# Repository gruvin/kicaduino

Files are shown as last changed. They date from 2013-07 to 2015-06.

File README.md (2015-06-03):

# KiCADuino
### A KiCAD version of the infamous Arduino UNO r3 PCB

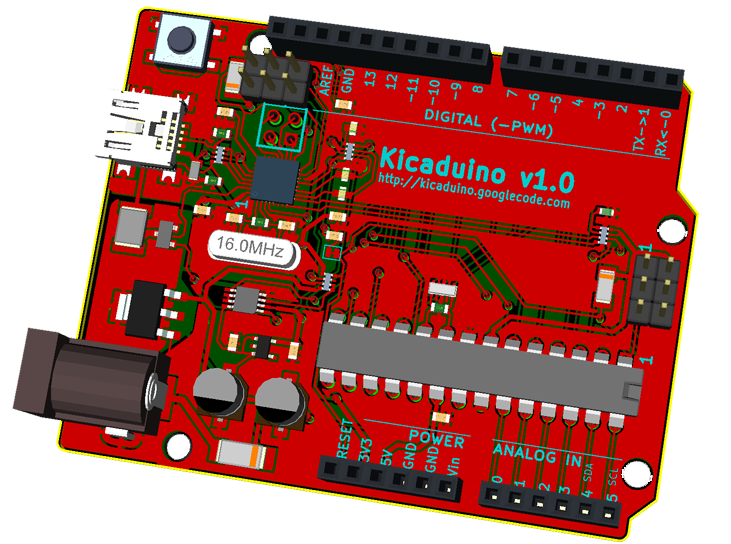
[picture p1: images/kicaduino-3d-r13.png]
There are too few, readily available and open projects in <a href='http://www.kicad-pcb.org'>KiCAD</a> 
format. I'm working to change that -- by taking some I like and re-creating them in KiCAD.

Why? Well, because it seemed a good idea and I seemed to have the time.

I'm starting with the good old Arduino UNO Rev.3, reference design. Obviously, my KiCAD version will not be an 
exact copy. In fact, I'll probably change the USB connector to USB-B-mini SMD. But otherwise, the circuitry 
will be the same, down to the socketed, DIP 'mega328. Maybe I'll do other versions later.

<blockquote>Arduino(TM) is a trademark of the owners of www.arduino.cc (they don't seem to have a name, other 
than Arduino -- even on their trademark information page). This KiCAD re-creation is by a 
separate individual, who is in no way related to the Arduino trademark owners or even likely 
known to them. Please see www.arduino.cc for all official Arduino(TM) information.</blockquote>

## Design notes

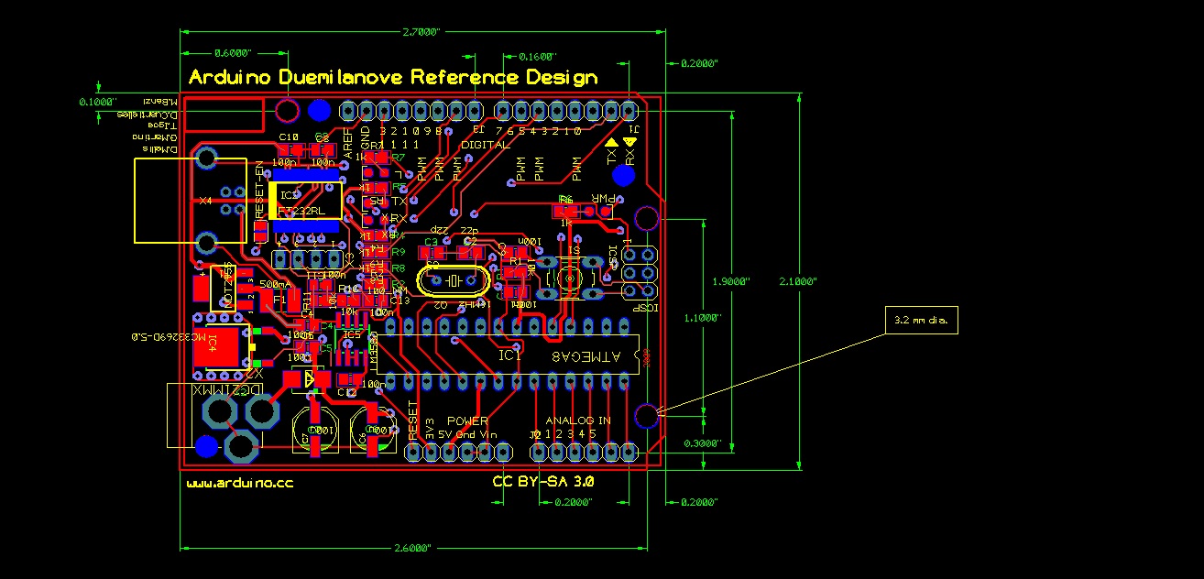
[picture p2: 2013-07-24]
uno/share/doc/Arduino Refererence Design.jpg

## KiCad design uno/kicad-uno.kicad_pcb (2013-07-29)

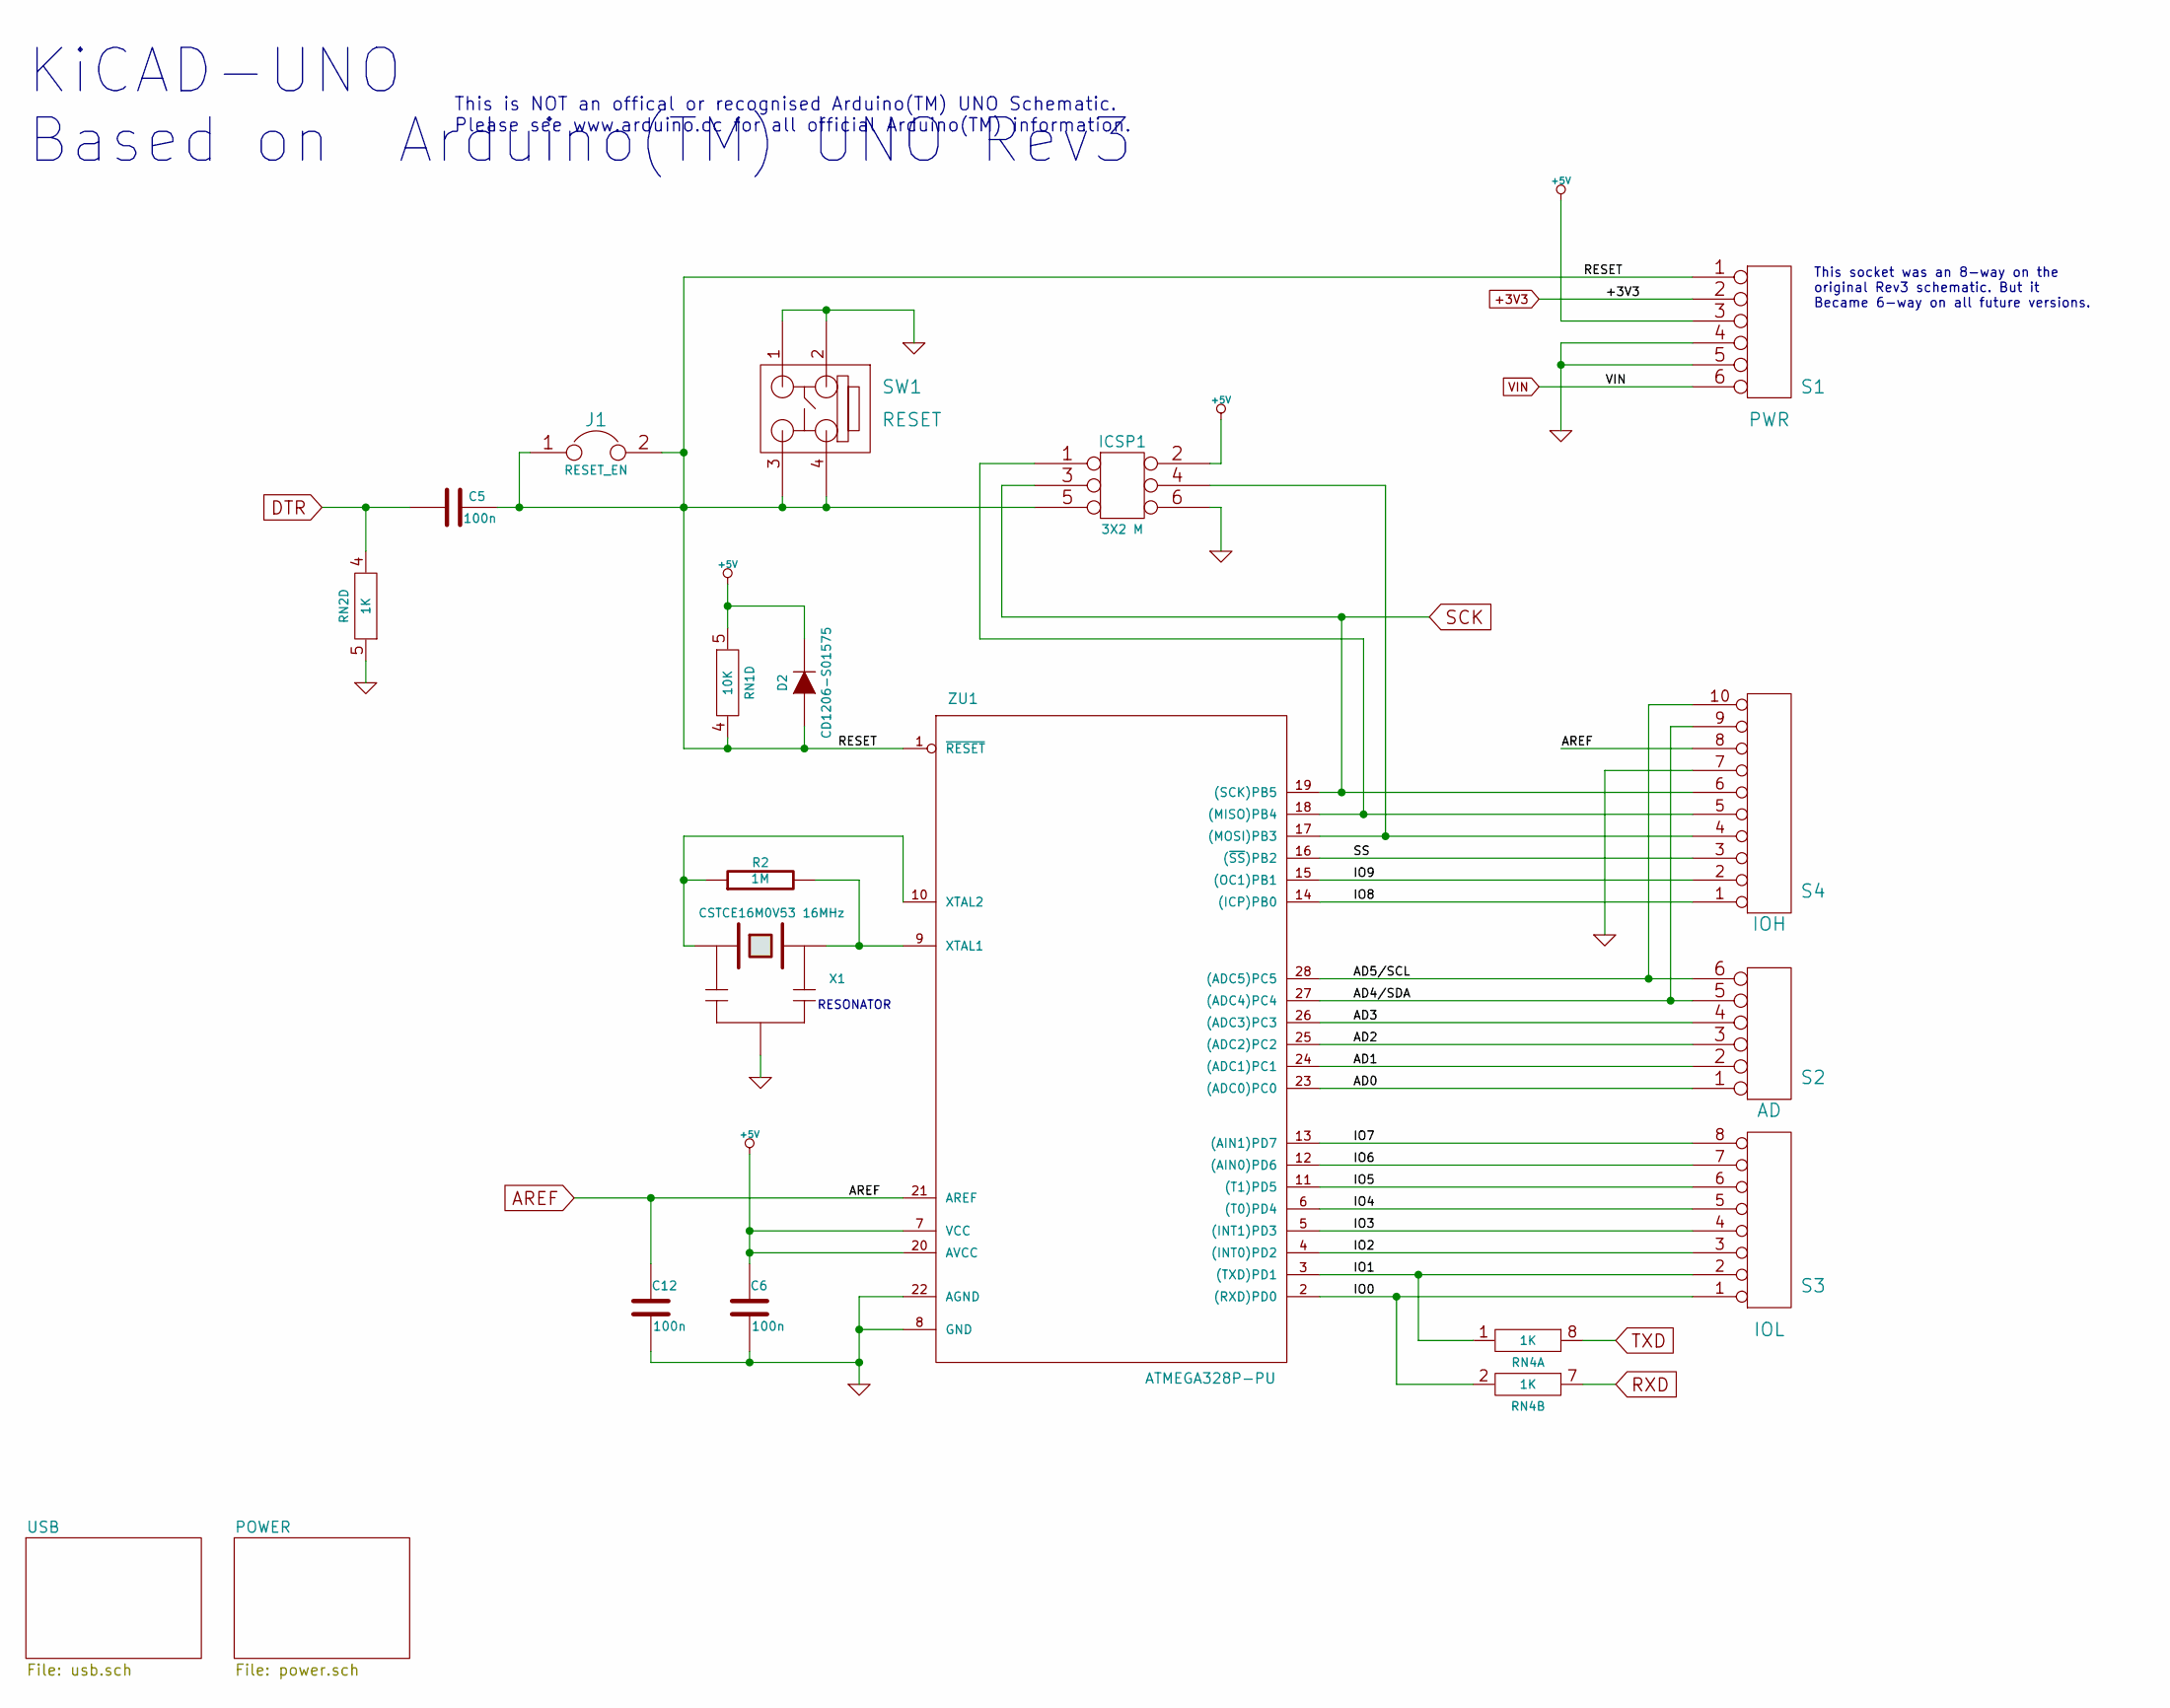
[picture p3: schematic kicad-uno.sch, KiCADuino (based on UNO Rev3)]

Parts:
C5, C6, C12: 100n; SM0603_Capa
D2: CD1206-S01575; SM1206D
ICSP1: 3X2 M; pin_array_3x2
J1: RESET_EN; JSOLD
R2: 1M
RN1: 10K
RN2, RN4: 1K
S1: PWR
S2: AD
S3: IOL
S4: IOH
SW1: RESET
X1: CSTCE16M0V53 16MHz
ZU1: ATMEGA328P-PU; DIP28

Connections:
+3V3: S1.2; also elsewhere on the board
+5V: C6.1, D2.2 (K), ICSP1.2, RN1.5 (6), S1.3, ZU1.7 (VCC), ZU1.20 (AVCC); also elsewhere on the board
/AD0: S2.1, ZU1.23 ((ADC0)PC0)
/AD1: S2.2, ZU1.24 ((ADC1)PC1)
/AD2: S2.3, ZU1.25 ((ADC2)PC2)
/AD3: S2.4, ZU1.26 ((ADC3)PC3)
/AD4/SDA: S2.5, S4.9, ZU1.27 ((ADC4)PC4)
/AD5/SCL: S2.6, S4.10, ZU1.28 ((ADC5)PC5)
/IO0: RN4.2 (3), S3.1, ZU1.2 ((RXD)PD0)
/IO1: RN4.1 (3), S3.2, ZU1.3 ((TXD)PD1)
/IO2: S3.3, ZU1.4 ((INT0)PD2)
/IO3: S3.4, ZU1.5 ((INT1)PD3)
/IO4: S3.5, ZU1.6 ((T0)PD4)
/IO5: S3.6, ZU1.11 ((T1)PD5)
/IO6: S3.7, ZU1.12 ((AIN0)PD6)
/IO7: S3.8, ZU1.13 ((AIN1)PD7)
/IO8: S4.1, ZU1.14 ((ICP)PB0)
/IO9: S4.2, ZU1.15 ((OC1)PB1)
/RESET: C5.2, D2.1 (A), ICSP1.5, J1.1, J1.2, RN1.4 (3), S1.1, SW1.3, SW1.4, ZU1.1 (~RESET)
/SS: S4.3, ZU1.16 ((~SS~)PB2)
AREF: C12.1, S4.8, ZU1.21 (AREF)
DTR: C5.1, RN2.4 (3); also elsewhere on the board
GND: C6.2, C12.2, ICSP1.6, RN2.5 (6), S1.4, S1.5, S4.7, SW1.1, SW1.2, X1.2, ZU1.8 (GND), ZU1.22 (AGND); also elsewhere on the board
unnamed: ICSP1.4, S4.4, ZU1.17 ((MOSI)PB3)
unnamed: ICSP1.1, S4.5, ZU1.18 ((MISO)PB4)
unnamed: R2.1, X1.1, ZU1.10 (XTAL2)
unnamed: R2.2, X1.3, ZU1.9 (XTAL1)
RXD: RN4.7 (6); also elsewhere on the board
SCK: ICSP1.3, S4.6, ZU1.19 ((SCK)PB5); also elsewhere on the board
TXD: RN4.8 (6); also elsewhere on the board
VIN: S1.6; also elsewhere on the board

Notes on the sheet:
RESONATOR
This is NOT an offical or recognised Arduino(TM) UNO Schematic. Please see www.arduino.cc for all official Arduino(TM) information.
KiCAD-UNO Based on Arduino(TM) UNO Rev3
This socket was an 8-way on the original Rev3 schematic. But it Became 6-way on all future versions.

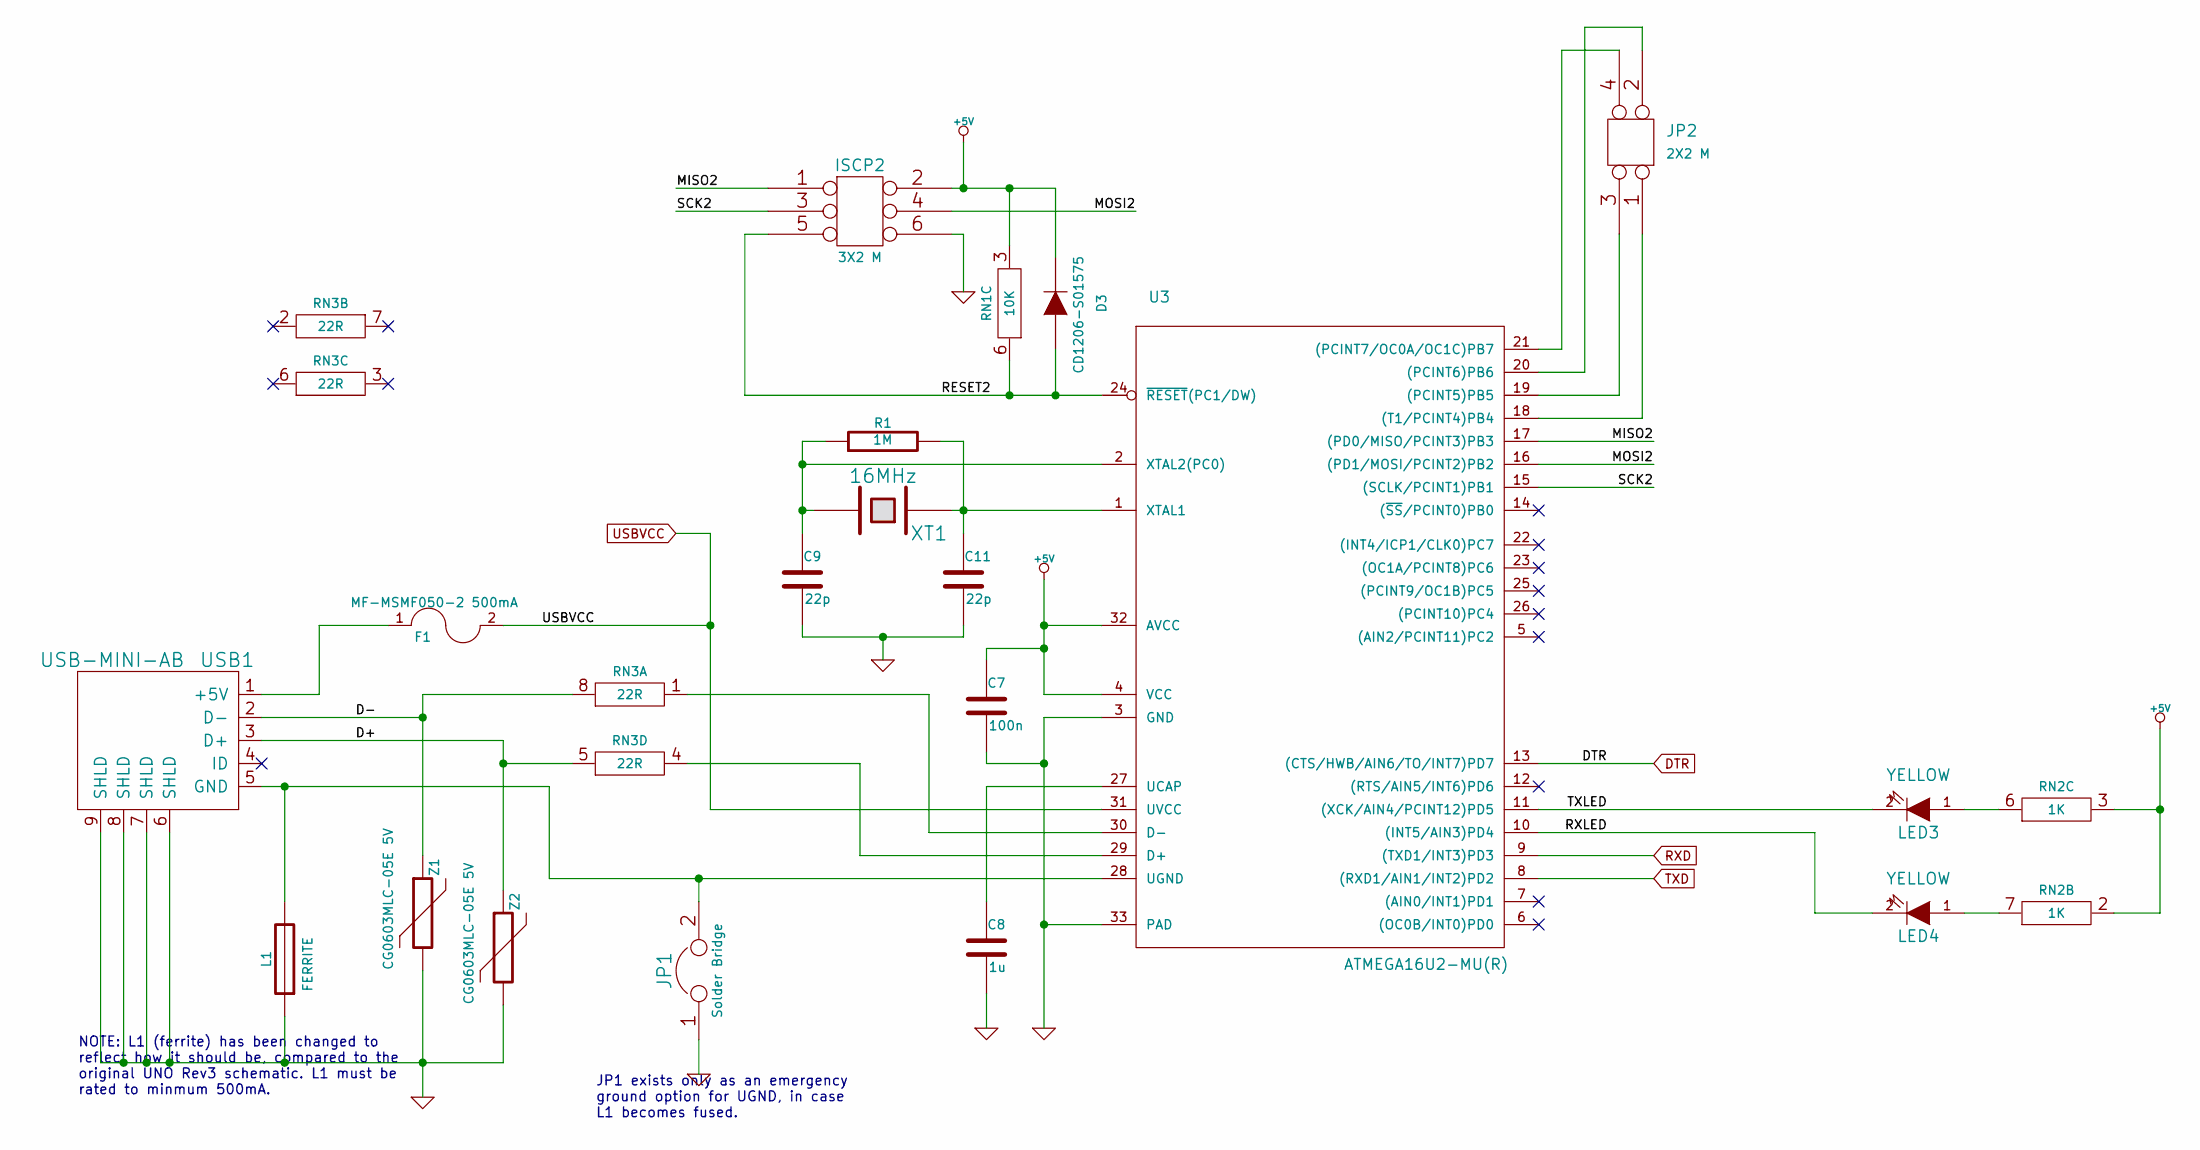
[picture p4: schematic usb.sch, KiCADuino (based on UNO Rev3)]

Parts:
C7: 100n; SM0603_Capa
C8: 1u; SM0603_Capa
C9, C11: 22p; SM0603_Capa
D3: CD1206-S01575; SM1206D
F1: MF-MSMF050-2 500mA; SM1812
ISCP2: 3X2 M; pin_array_3x2
JP1: Solder Bridge
JP2: 2X2 M; PIN_ARRAY_2X2
L1: FERRITE; SM0805
LED3, LED4: YELLOW
R1: 1M
RN1: 10K
RN2: 1K
RN3: 22R
U3: ATMEGA16U2-MU(R); QFN32
USB1: USB-MINI-AB
XT1: 16MHz
Z1, Z2: CG0603MLC-05E 5V

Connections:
+5V: C7.1, D3.2 (K), ISCP2.2, RN1.3, RN2.2 (3), RN2.3, U3.4 (VCC), U3.32 (AVCC); also elsewhere on the board
/USB/D+: RN3.5 (6), USB1.3 (D+), Z2.1
/USB/D-: RN3.8 (6), USB1.2 (D-), Z1.1
/USB/MISO2: ISCP2.1, U3.17 ((PD0/MISO/PCINT3)PB3)
/USB/MOSI2: ISCP2.4, U3.16 ((PD1/MOSI/PCINT2)PB2)
/USB/RESET2: D3.1 (A), ISCP2.5, RN1.6, U3.24 (~RESET~(PC1/DW))
/USB/RXLED: LED4.2 (K), U3.10 ((INT5/AIN3)PD4)
/USB/SCK2: ISCP2.3, U3.15 ((SCLK/PCINT1)PB1)
/USB/TXLED: LED3.2 (K), U3.11 ((XCK/AIN4/PCINT12)PD5)
DTR: U3.13 ((CTS/HWB/AIN6/TO/INT7)PD7); also elsewhere on the board
GND: C7.2, C8.2, C9.2, C11.2, ISCP2.6, JP1.1, L1.1, U3.3 (GND), U3.33 (PAD), USB1.6 (SHLD), USB1.7 (SHLD), USB1.8 (SHLD), USB1.9 (SHLD), Z1.2, Z2.2; also elsewhere on the board
unnamed: JP2.4, U3.21 ((PCINT7/OC0A/OC1C)PB7)
unnamed: JP2.3, U3.19 ((PCINT5)PB5)
unnamed: JP2.2, U3.20 ((PCINT6)PB6)
unnamed: C8.1, U3.27 (UCAP)
unnamed: JP2.1, U3.18 ((T1/PCINT4)PB4)
unnamed: LED3.1 (A), RN2.6
unnamed: F1.1, USB1.1 (+5V)
unnamed: LED4.1 (A), RN2.7 (6)
unnamed: RN3.4 (3), U3.29 (D+)
unnamed: RN3.1 (3), U3.30 (D-)
unnamed: C9.1, R1.1, U3.2 (XTAL2(PC0)), XT1.2
unnamed: C11.1, R1.2, U3.1 (XTAL1), XT1.1
unnamed: JP1.2, L1.2, U3.28 (UGND), USB1.5 (GND)
RXD: U3.9 ((TXD1/INT3)PD3); also elsewhere on the board
TXD: U3.8 ((RXD1/AIN1/INT2)PD2); also elsewhere on the board
USBVCC: F1.2, U3.31 (UVCC); also elsewhere on the board

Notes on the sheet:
NOTE: L1 (ferrite) has been changed to reflect how it should be, compared to the original UNO Rev3 schematic. L1 must be rated to minmum 500mA.
JP1 exists only as an emergency ground option for UGND, in case L1 becomes fused.

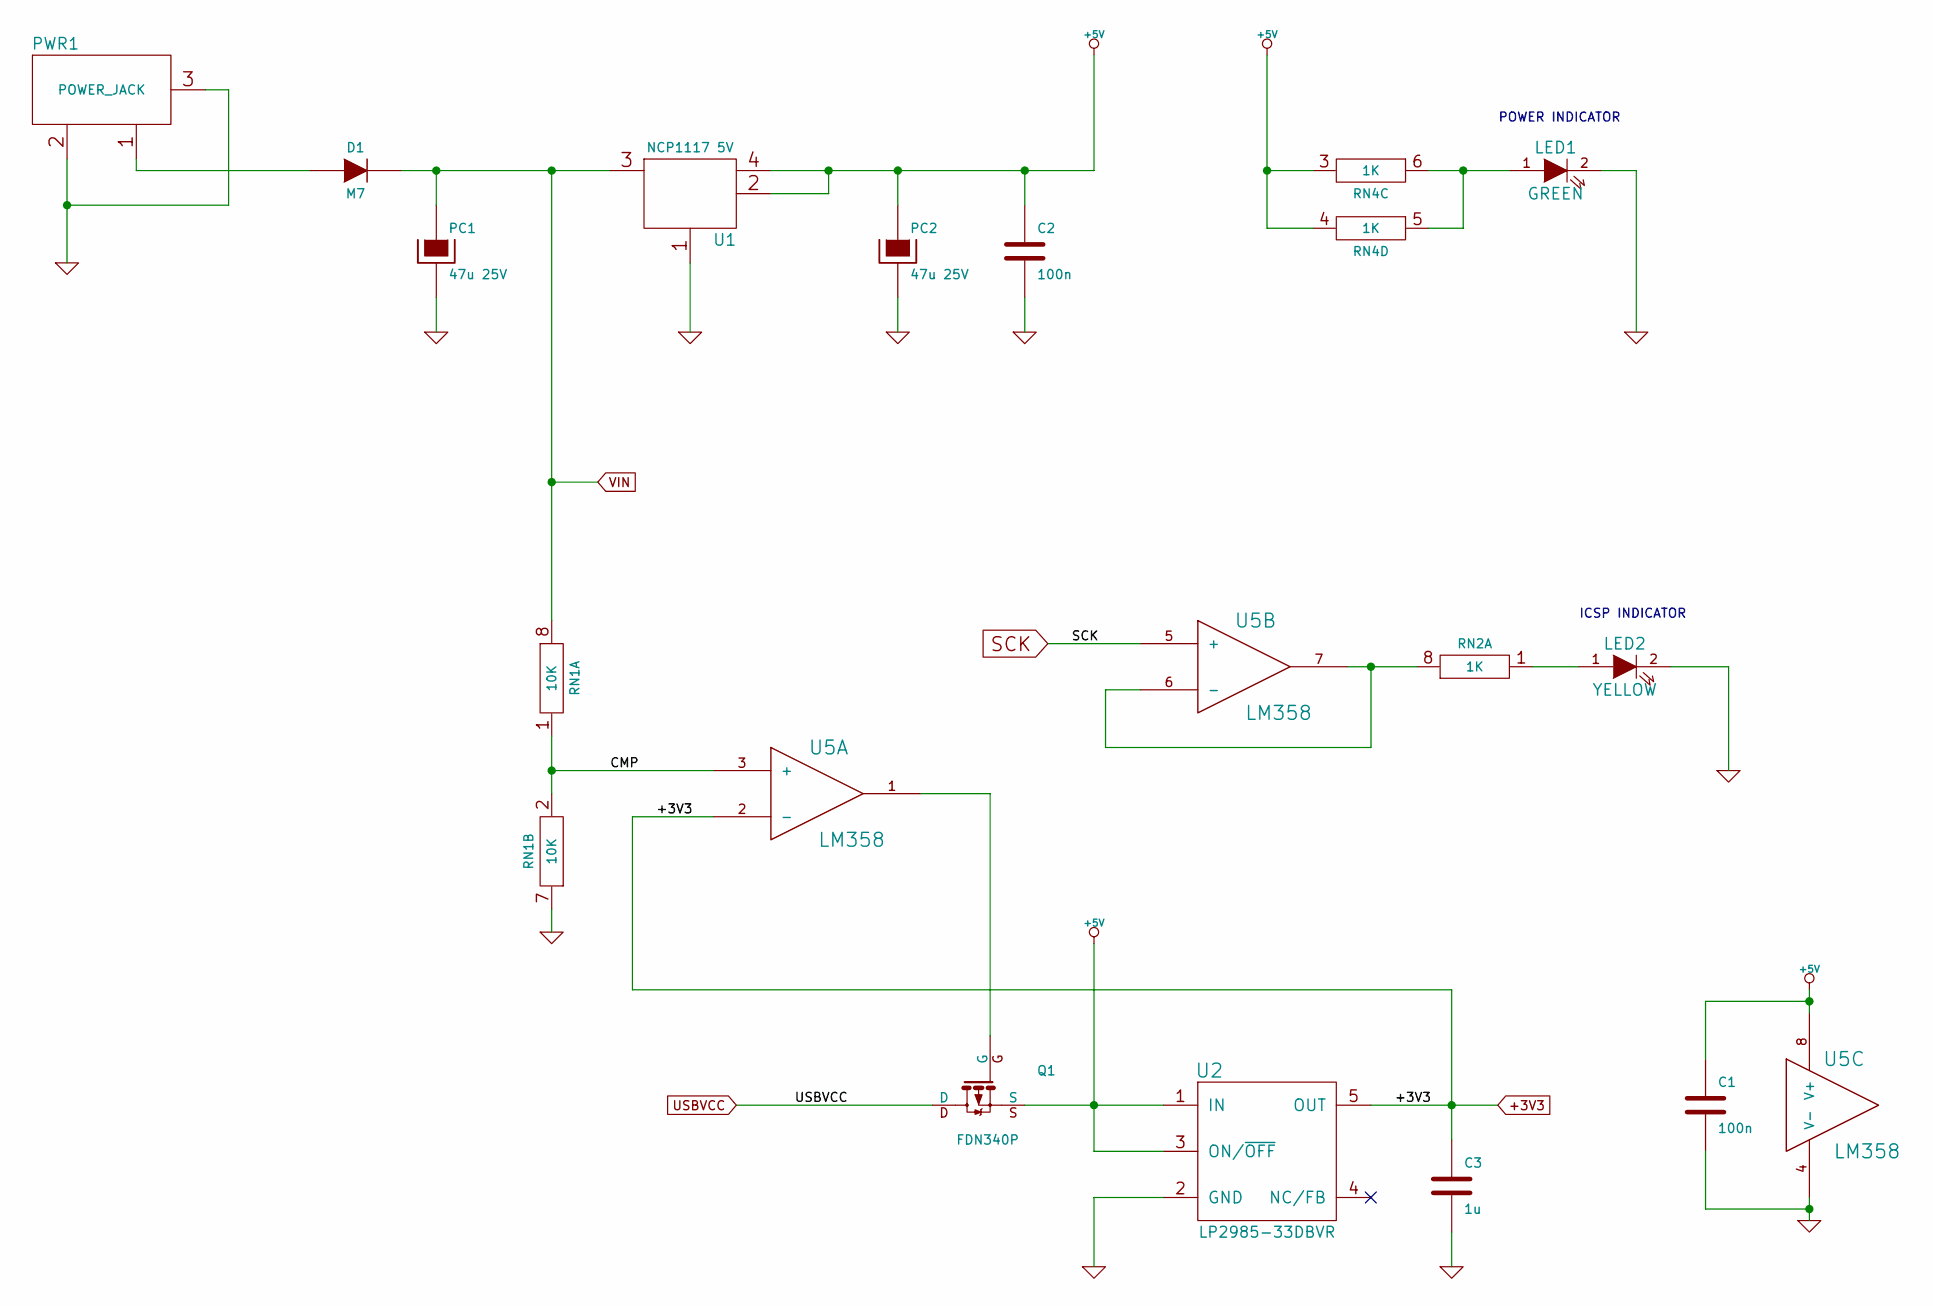
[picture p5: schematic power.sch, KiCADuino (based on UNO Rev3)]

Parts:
C1, C2: 100n; SM0603_Capa
C3: 1u; SM0603_Capa
D1: M7; DO-214AC
LED1: GREEN; LED_0603_GREEN
LED2: YELLOW
PC1, PC2: 47u 25V
PWR1: POWER_JACK
Q1: FDN340P; SOT23
RN1: 10K
RN2, RN4: 1K
U1: NCP1117 5V
U2: LP2985-33DBVR
U5: LM358

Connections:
+3V3: C3.1, U2.5 (OUT), U5.2 (-); also elsewhere on the board
+5V: C1.1, C2.1, PC2.1, Q1.S, RN4.3, RN4.4 (3), U1.2 (PM), U1.4 (OUT), U2.1 (IN), U2.3 (ON/~OFF~), U5.8 (V+); also elsewhere on the board
/POWER/CMP: RN1.1 (3), RN1.2 (3), U5.3 (+)
GND: C1.2, C2.2, C3.2, LED1.2 (K), LED2.2 (K), PC1.2, PC2.2, PWR1.2, PWR1.3, RN1.7 (6), U1.1 (GND), U2.2 (GND), U5.4 (V-); also elsewhere on the board
unnamed: Q1.G, U5.1
unnamed: LED2.1 (A), RN2.1 (3)
unnamed: RN2.8 (6), U5.6 (-), U5.7
unnamed: LED1.1 (A), RN4.5 (6), RN4.6
unnamed: D1.1 (A), PWR1.1
SCK: U5.5 (+); also elsewhere on the board
USBVCC: Q1.D; also elsewhere on the board
VIN: D1.2 (K), PC1.1, RN1.8 (6), U1.3 (IN); also elsewhere on the board

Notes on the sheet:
POWER INDICATOR
ICSP INDICATOR

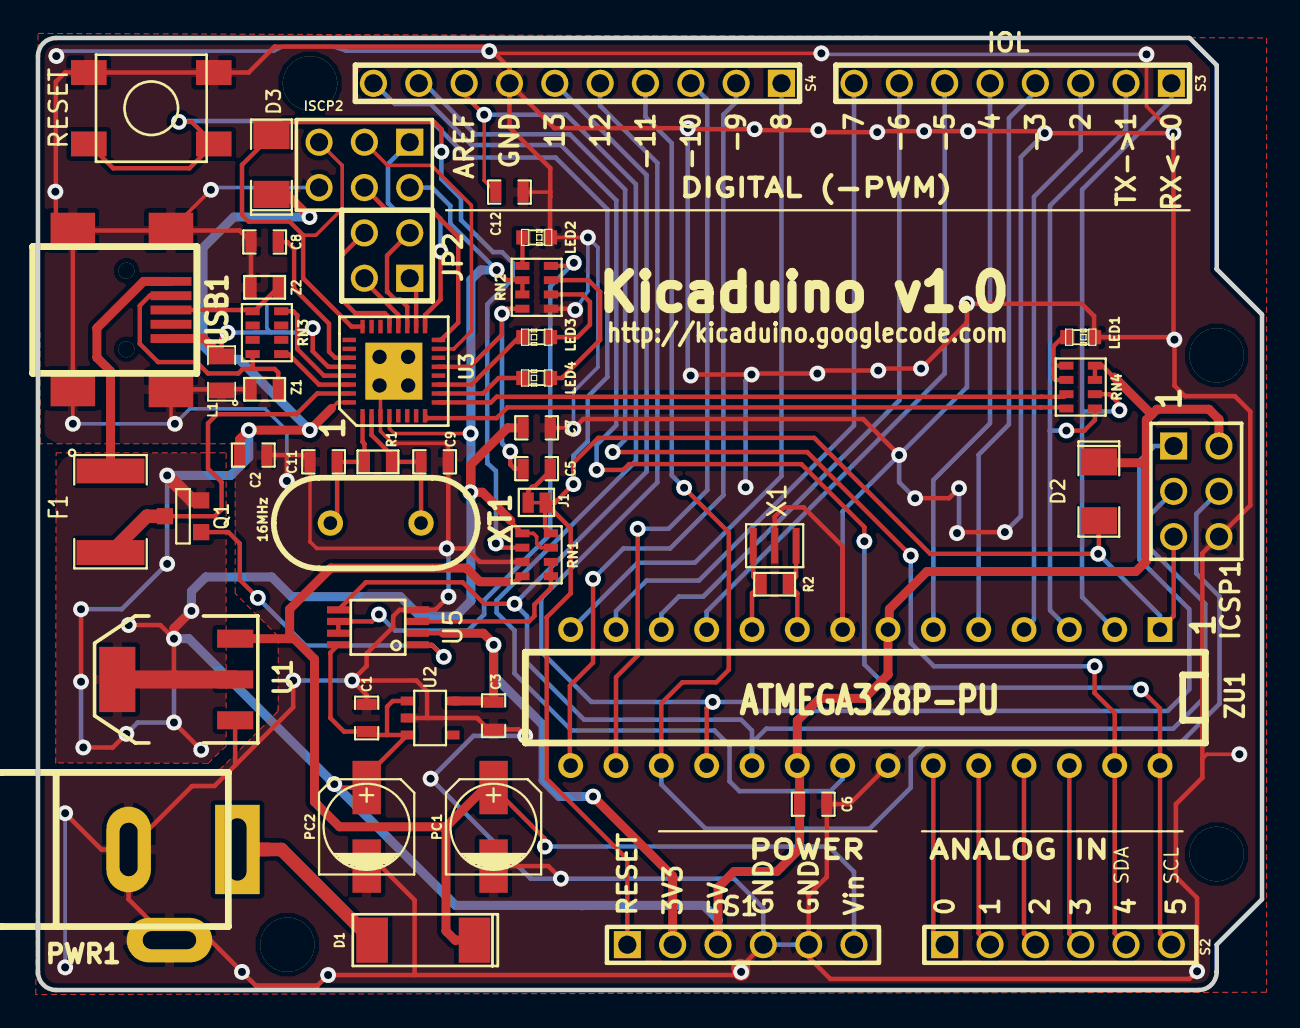
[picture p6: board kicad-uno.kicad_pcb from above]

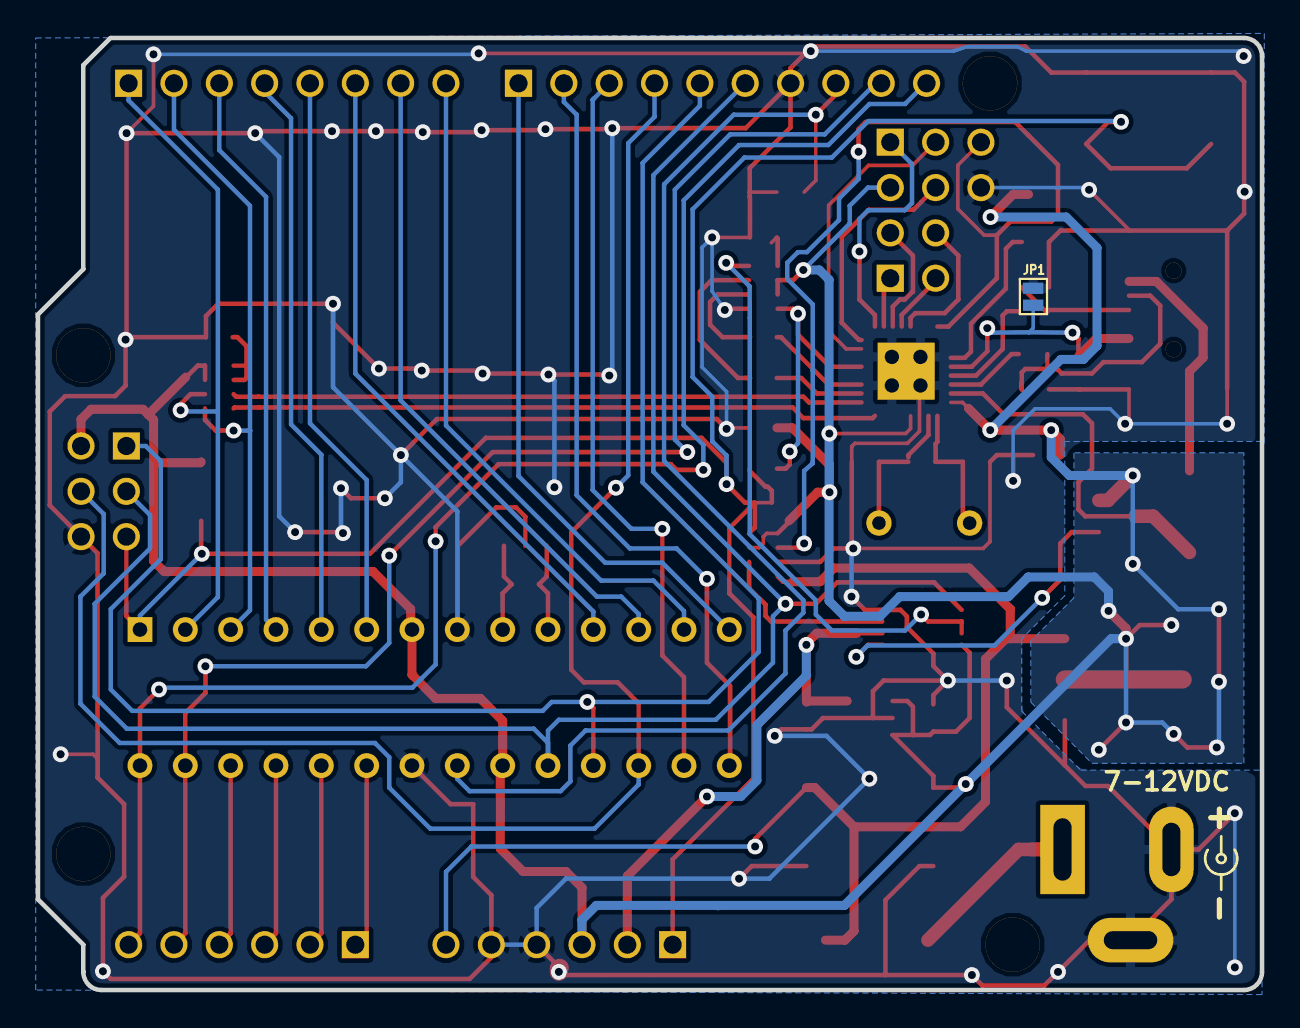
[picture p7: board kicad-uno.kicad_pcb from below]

Board: 2 copper layers, 68.6 x 53.3 mm, 54 parts (2 on the bottom side), 59 nets.

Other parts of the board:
HOLE_130x130mil, HOLE_130x130mil#2, HOLE_130x130mil#3, HOLE_130x250mil: VAL**; HOLE_120x120mil
REF: VAL**; POWER_POLARITY_REF

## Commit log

2013-07-24 Schematic ERC passes. Circuit _might_ be complete, without errors. You just never know. :-P
    [kicad-uno.sch, power.sch, usb.sch]
2013-07-25 Component packages configured.
    PCB initial placement.
    Some minor typo corrections.
    [kicad-uno.kicad_pcb, kicad-uno.sch, power.sch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]
2013-07-25 Added resistor network part/module for RN1-4 (no 3D package yet).
    [kicad-uno.kicad_pcb, kicad-uno.sch, power.sch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]
2013-07-25 Board edges completed.
    [kicad-uno.kicad_pcb]
2013-07-25 About half the comoponents placed, in the exact same location as the UNO Rev3 reference design, except I changed the USB socket to a mini.
    A number of minor schematic errors were corrected, around the pin
    numbering of the four resistor network chips.
    [kicad-uno.kicad_pcb, kicad-uno.sch, power.sch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]
2013-07-26 All components placed. Some routing started.
    [kicad-uno.kicad_pcb, kicad-uno.sch, power.sch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]
2013-07-27 More routing.
    [kicad-uno.kicad_pcb, usb.sch]
2013-07-27 Routing complete. Board complete.
    Just need to do the 3D packages for the resistor arrays and rsonator.
    Oh -- the previous revisions had the wrong size resistor array parts. That
    was corrected in this version. (SM0402, apparently.)
    [kicad-uno.kicad_pcb]
2013-07-28 Board fully completed v1.0.
    [kicad-uno-B_Cu.gbl, kicad-uno-B_Mask.gbs, kicad-uno-B_SilkS.gbo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]
2013-07-28 Mounting holes added. Had to move the power jack out a bit.
    [kicad-uno-B_Cu.gbl, kicad-uno-B_Mask.gbs, kicad-uno-B_SilkS.gbo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]
2013-07-29 Changed the resistor networks from 0402 to 0603 size, per the original Arduino UNO reference design (I think!)
    [kicad-uno.kicad_pcb]
2013-07-29 Previous change may not have been fully saved. Fixed in this commit.
    [kicad-uno.kicad_pcb]
2013-07-29 Minor track spacing changes, just to reduce copper etch some.
    [kicad-uno.kicad_pcb]
2016-11-25 UNO production files
    [kicad-uno-B_Cu.gbl, kicad-uno-B_Mask.gbs, kicad-uno-B_SilkS.gbo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]
